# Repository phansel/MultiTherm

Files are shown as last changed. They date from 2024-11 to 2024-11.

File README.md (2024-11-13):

# MultiTherm
This repository contains the hardware, firmware, and drivers for MultiTherm.

MultiTherm allows you to log data from a few [tiny I2C temperature sensors](https://www.ti.com/lit/ds/symlink/tmp117.pdf) via your computer's USB port. A few could range from 1-4 or more.

Each temperature sensor is on a flexible 200mm probe ribbon; route them in free space however you like, or even trim their ribbons to length. An adhesive sticker provides thermal coupling to your device under test.

MultiTherm can be used as a lower-cost substitute for a resistance temperature detector (RTD) and data acquisition interface (DAQ) while still featuring NIST-traceable calibration accurate within ±0.1°C (between –20°C to 50°C) and 0.0078°C read-out resolution.

Working temperature range is –55 °C to 150 °C.

MultiTherm will be made available for purchase at a later date.

## Applications
- Optical bench temperature compensation
- Bulk material conductivity measurement
- Power electronics testing and characterization
- Chemical synthesis
- Bioreactors, polymerase chain reaction
- Wearable devices

## Project structure
- ESP32C6 firmware: [mt-fw](./mt-fw)
- PCB design files: [mt-hw](./mt-hw)
- Userspace serial-to-npyz driver: [mt-relay](./mt-relay)
- Project roadmap: [ROADMAP.md](./ROADMAP.md)

## License
[GPLv3](./LICENSE)

## Copyright
[Paul Hansel](https://paulhansel.com), 2024

## Thanks to:
- [Rust on ESP community](https://github.com/esp-rs)
- [KiCAD developers](https://www.kicad.org/sponsors/sponsors/)
- [Rust Embedded Working Group](https://blog.rust-embedded.org/)

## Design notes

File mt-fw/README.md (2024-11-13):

# MultiTherm ESP32C6 firmware

To build: `cargo build --release` or `./d.sh`

To flash: `cargo run --release` or `./r.sh`

Pinout for ESP32C6:
- I2C SDA: IO19, 
- I2C SCL: IO20

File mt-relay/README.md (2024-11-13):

# MultiTherm serial-to-npz relay

Converts an incoming stream of data from a MultiTherm connected over USB serial to a NumPy Zip ([npyz](https://numpy.org/doc/stable/reference/generated/numpy.lib.format.html)).

Bill of Materials:
- [serialport](https://github.com/serialport/serialport-rs) = "4.6.0"
- [nalgebra](https://docs.rs/nalgebra/latest/nalgebra/) = "0.33.2"
- [npyz](https://github.com/ExpHP/npyz) = "0.8"

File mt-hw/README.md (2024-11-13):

# MultiTherm Hardware
Printed circuit board and flex PCB design files.

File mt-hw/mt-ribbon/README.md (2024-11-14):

# MultiTherm Ribbon
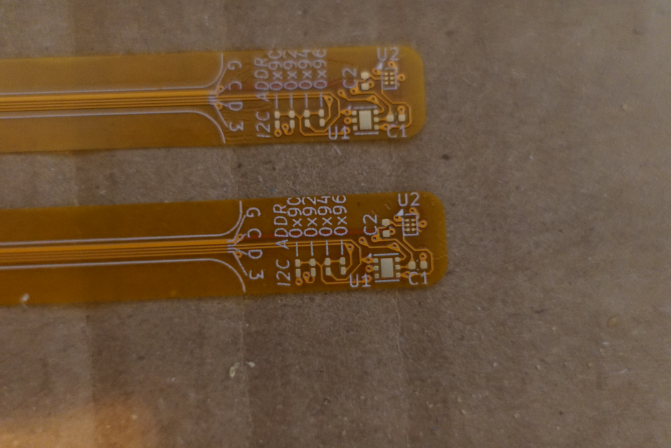
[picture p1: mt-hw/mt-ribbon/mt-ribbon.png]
Unpopulated mt-ribbon flex PCB


Individual ribbon cable flex PCB with temperature probe on the end.

Device address is configurable via solderable jumpers.

Supports WSON-6 (TMP117xxDRV) and DSBGA (TMP117xxYBG) packages. Populate one.

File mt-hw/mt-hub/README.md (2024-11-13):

# MultiTherm Hub
A hub for multiple MultiTherm probe ribbons.

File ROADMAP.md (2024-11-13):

# Roadmap
[X] Complete initial requirements document
[X] Publish PCB schematic and layout (GPLv3)
[X] Publish firmware (GPLv3)
[X] Publish userspace driver (GPLv3)
[ ] Project write-up
[ ] Ship integrated product (USB hub PCB, ribbons, documentation) to market

## Hardware
[X] Ribbon probe PCB schematic
[X] Ribbon probe PCB layout
[X] Fabricate and validate probe ribbon PCB (Rev 1.0)
[ ] Fabricate and validate probe ribbon PCB (Rev 1.2)
[ ] Model thermal resistance parameters of probe ribbon
[ ] Characterize thermal resistance of probe ribbon
[ ] Convert pin headers on probe ribbon to FFC
[ ] Write requirements for sensor hub: USB port, MCU, 0.1" headers, pull-up resistors, flat flex connectors.
[ ] Part selection for sensor hub
[ ] Sensor hub PCB schematic
[ ] Sensor hub PCB layout
[ ] Fabricate and validate sensor hub PCB

## Firmware
[X] Write minimal TMP117 driver
[X] Complete serial data format specification
[X] Write microcontroller firmware bridging TMP117 to serial (ESP32C6)
[ ] Replace ad-hoc TMP117 driver with [tmp117-rs](https://github.com/xgroleau/tmp117-rs)
[ ] Port firmware to lower-cost USB-serial microcontrollers: RP2040/RP2350/CH32V

## Software
[X] Write userspace driver bridging serial stream to .npyz timeseries with Unix timestamp
[X] Validate userspace driver end-to-end with application
[ ] Generalize userspace driver to remove assumption of three sensors
[ ] Create udev rules to automatically start and stop userspace driver when device is connected
[ ] Validate that udev rules behave as expected
[ ] Make userspace driver persistent to device serial connection interruptions: don't reset timeseries
[ ] Enable [atomic filesystem writes](https://github.com/danburkert/fs2-rs) for serial-to-file userspace driver 
[ ] Convert userspace driver to [kernel space driver](https://not-matthias.github.io/posts/kernel-driver-with-rust-2022/)
[ ] Add macOS and Windows support

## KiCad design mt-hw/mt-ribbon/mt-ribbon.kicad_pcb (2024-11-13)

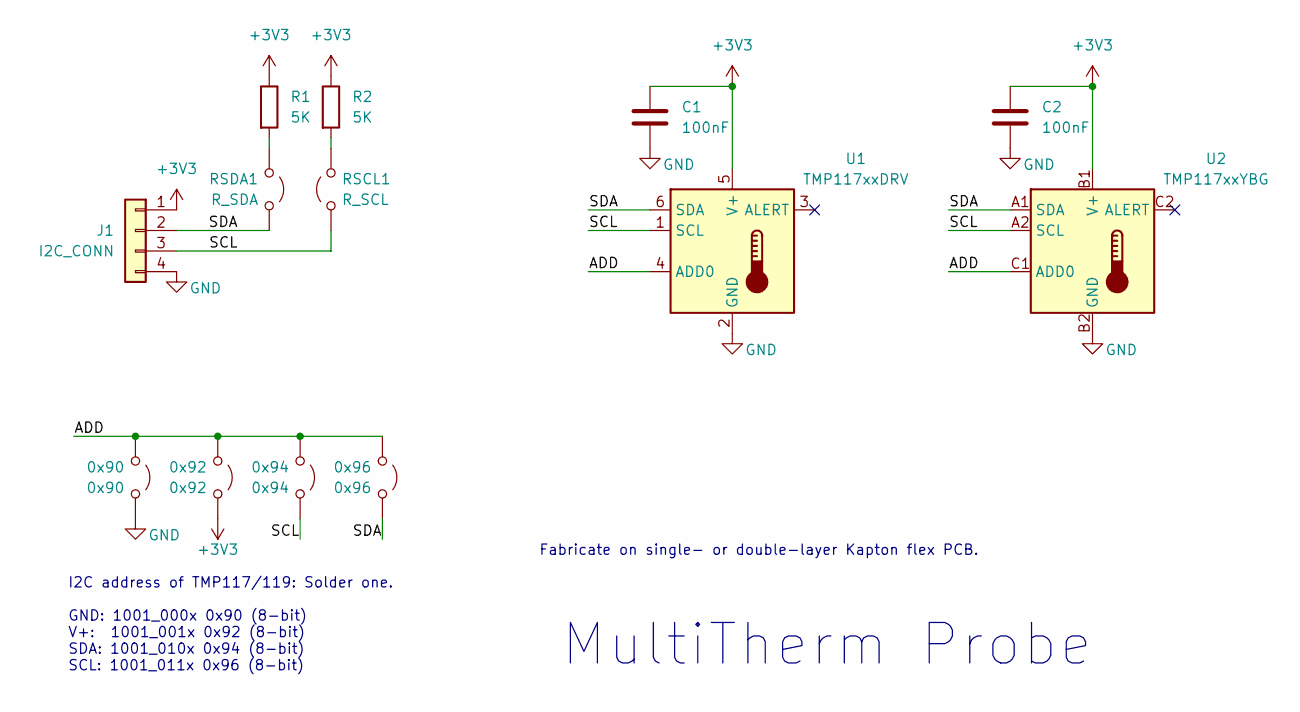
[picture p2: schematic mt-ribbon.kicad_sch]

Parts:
0x90: 0x90; SolderJumper-2_P0.43mm_Open_Pad0.3x0.75mm
0x92: 0x92; SolderJumper-2_P0.43mm_Open_Pad0.3x0.75mm
0x94: 0x94; SolderJumper-2_P0.43mm_Open_Pad0.3x0.75mm
0x96: 0x96; SolderJumper-2_P0.43mm_Open_Pad0.3x0.75mm
C1, C2: 100nF; C_0402_1005Metric
J1: I2C_CONN; PinHeader_1x04_P2.54mm_Vertical
R1, R2: 5K; R_0402_1005Metric_Pad0.72x0.64mm_HandSolder
RSCL1: R_SCL; SolderJumper-2_P0.43mm_Open_Pad0.3x0.75mm
RSDA1: R_SDA; SolderJumper-2_P0.43mm_Open_Pad0.3x0.75mm
U1: TMP117xxDRV; WSON-6-1EP_2x2mm_P0.65mm_EP1x1.6mm
U2: TMP117xxYBG; Texas_DSBGA-6_0.95x1.488mm_Layout2x3_P0.4mm

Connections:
+3V3: 0x92.1 (A), C1.1, C2.1, J1.1, R1.1, R2.1, U1.5 (V+), U2.B1 (V+)
/ADD: 0x90.2 (B), 0x92.2 (B), 0x94.2 (B), 0x96.2 (B), U1.4 (ADD0), U2.C1 (ADD0)
/SCL: 0x94.1 (A), J1.3, RSCL1.1 (A), U1.1 (SCL), U2.A2 (SCL)
/SDA: 0x96.1 (A), J1.2, RSDA1.1 (A), U1.6 (SDA), U2.A1 (SDA)
GND: 0x90.1 (A), C1.2, C2.2, J1.4, U1.2 (GND), U2.B2 (GND)
unnamed: R2.2, RSCL1.2 (B)
unnamed: R1.2, RSDA1.2 (B)

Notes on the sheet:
I2C address of TMP117/119: Solder one. GND: 1001_000x 0x90 (8-bit) V+: 1001_001x 0x92 (8-bit) SDA: 1001_010x 0x94 (8-bit) SCL: 1001_011x 0x96 (8-bit)
Fabricate on single- or double-layer Kapton flex PCB.
MultiTherm Probe

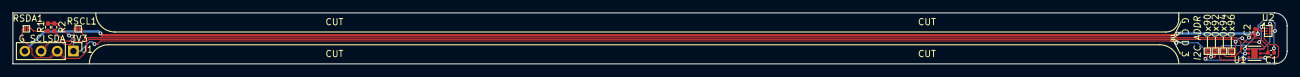
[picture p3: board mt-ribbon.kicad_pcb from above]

Board: 2 copper layers, 200.0 x 8.0 mm, 13 parts (0 on the bottom side), 7 nets.

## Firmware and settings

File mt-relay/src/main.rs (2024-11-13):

// Read temperatures sequentially from serial
// Write array sequence to files (/tmp/tempdataline) as npyz
// Other programs can read npyz periodically as required

use serialport;
use std::io::BufRead;
use std::io::BufReader;
use std::time::{Duration, Instant, SystemTime, UNIX_EPOCH};

use std::vec::Vec;

// TODO: flush samples more intelligently
const TSAMPS_FLUSH_THRESH: usize = 1500;
const TSAMPS_FLUSH_TARGET: usize = 1025;
const TDIFF_CUTOFF_MS: u128 = 750; // fudge factor

fn main() {
    let mut temp_seq: [[u16; 3]; 16] = [[0; 3]; 16];

    let serialport = "/dev/ttyACM0";
    let bitrate = 115200;
    let data_filename = "/tmp/tempdataline";

    // timestamp durations in the past
    // should be reconstructed / interpolated from existing values
    let time_samples_dt = [
        0.0, 1.0, 2.0, 4.0, 8.0, 16.0, 32.0, 64.0, 128.0, 256.0, 512.0, 1024.0, 2048.0, 4096.0,
        8192.0, 16384.0,
    ];

    // whether each of the samples in the line is valid (if not valid, set to 0)
    let mut time_samples_valid = [0_u8; 16];

    println!("Launching serial tempdata relay!");

    let mut tsamps: Vec<(std::time::Instant, [u16; 3])> = Vec::new();

    let serial_port = serialport::new(serialport, bitrate)
        .timeout(Duration::from_millis(1000))
        .open()
        .expect("Failed to open serial port.");

    let mut reader = BufReader::new(serial_port);

    // TODO: remove coupling to three sensors
    let addr_arr = [0x48_u8, 0x49_u8, 0x4A_u8];

    let mut buffer = "".to_string(); // enough bytes to read one line of temp samples
    loop {
        buffer = "".to_string();
        let read = reader.read_line(&mut buffer).unwrap();
        let current_time = Instant::now();
        let actual_now = SystemTime::now()
            .duration_since(UNIX_EPOCH)
            .expect("Time went backwards")
            .as_secs() as u128;

        let x = string_to_temps(buffer);

        let y = map_tr_to_arr(x, addr_arr);

        if let Some(y) = y {
            tsamps.push((current_time, y));
            (tsamps, temp_seq) = process_samples(tsamps, &time_samples_dt, &mut time_samples_valid);
            match write_ts_data_file(data_filename.to_string(), actual_now, temp_seq) {
                Ok(_) => {}
                Err(e) => {
                    panic!("Fault: {e}");
                }
            }
        }
    }
}

/*
Example output from the serial port:
[48:1606][49:1665][4a:1314]
[48:1606][49:1666][4a:1313]
[48:1606][49:1666][4a:1313]
temp at 0x48: 40.632813 C
temp at 0x49: 33.992188 C
temp at 0x4a: 24.695313 C

*/



#[derive(npyz::Serialize, npyz::Deserialize, npyz::AutoSerialize, Debug, PartialEq, Clone)]
pub struct SampleBlob {
    // TODO: remove coupling to three sensors
    arr: [[u16; 3]; 16],
    timestamp: [u32; 4],
}

// docs: https://docs.rs/npyz/latest/npyz/
pub fn write_ts_data_file(fname: String, ts: u128, arr: [[u16; 3]; 16]) -> std::io::Result<()> {
    // TODO: remove coupling to three sensors
    let mut out_buf: Vec<SampleBlob> = vec![];
    let mut structs = vec![];

    let tsu32 = [
        ts as u32,
        (ts >> 32) as u32,
        (ts >> 64) as u32,
        (ts >> 96) as u32,
    ];

    let calBlob = SampleBlob {
        arr: arr,
        timestamp: tsu32,
    };

    structs.push(calBlob);

    npyz::to_file_1d(fname.to_string(), structs)?;

    Ok(())
}

pub fn process_samples(
    mut tsamps: Vec<(std::time::Instant, [u16; 3])>,
    sample_deltas: &[f32; 16],
    mut mask_valid: &mut [u8; 16],
) -> (Vec<(std::time::Instant, [u16; 3])>, [[u16; 3]; 16]) {
    // TODO: remove coupling to three sensors
    let mut temp_hist_arr = [[0xFFFF_u16; 3]; 16];

    let time_now = Instant::now();

    // sample the data points and interpolate, and also cull extra points if over 1000
    if tsamps.len() > TSAMPS_FLUSH_THRESH {
        let mut tsamps_new: Vec<(std::time::Instant, [u16; 3])> = Vec::new();
        let todrain = TSAMPS_FLUSH_TARGET;

        for i in 0..todrain {
            tsamps_new.push(tsamps[i + todrain - 1]);
        }
        tsamps = tsamps_new;
    }

    // wipe out the mask if we don't have samples back then
    let oldest_delta = ((time_now - tsamps[0].0).as_millis() as f32) / 1000.0;
    let mut n_valid = 0;
    for i in 0..mask_valid.len() {
        if sample_deltas[i] > oldest_delta {
            mask_valid[i] = false as u8;
        } else {
            mask_valid[i] = true as u8;
            n_valid += 1;
        }
    }

    // sample tsamps at sample_deltas offsets from time_now
    // is this inefficient? why not
    for i in 0..n_valid {
        let target_tdiff = (sample_deltas[i] * 1000.0) as u128;
        for (time, tempvals) in &tsamps {
            if ((time_now - *time).as_millis() - target_tdiff) < TDIFF_CUTOFF_MS {
                temp_hist_arr[i] = *tempvals;
                break;
            }
        }
        if temp_hist_arr[i] == [0xFFFF_u16; 3] {
            // todo: if we didn't get it with nearest neighbor, try interp
            // println!("Didn't get it on n{}", i);
        }
    }

    return (tsamps, temp_hist_arr);
}

pub fn map_tr_to_arr(temps: [(u8, u16); 3], addr_arr: [u8; 3]) -> Option<[u16; 3]> {
    // TODO: remove coupling to three sensors
    let mut temps2 = [0_u16; 3];
    let mut incr = 0;
    for addr in addr_arr {
        for temp in temps {
            if temp.0 == addr {
                temps2[incr] = temp.1;
                incr += 1;
            }
        }
    }
    if incr == 3 {
        return Some(temps2);
    } else {
        return None;
    }
}

pub fn string_to_temps(instr: String) -> [(u8, u16); 3] {
    // TODO: remove coupling to three sensors
    let mut outdata = [(0_u8, 0_u16); 3];

    let instr = instr.trim();

    match instr.chars().nth(0) {
        Some('[') => {}
        _ => {
            println!("Not a valid string! Should probably error.");
            return [(0_u8, 0_u16); 3];
        }
    };

    match instr.chars().nth(26) {
        Some(']') => {}
        _ => {
            println!("Not a valid string! Should probably error.");
            return [(0_u8, 0_u16); 3];
        }
    };

    // [48:1606][49:1666][4a:1313]

    let (addr1, data1) = (&instr[1..3], &instr[4..8]);
    let (addr2, data2) = (&instr[10..12], &instr[13..17]);
    let (addr3, data3) = (&instr[19..21], &instr[22..26]);

    // println!("vals: {}_{}, {}_{}, {}_{}", addr1, data1, addr2, data2, addr3, data3);

    // now put it into outdata
    // convert each str to a u16 or u8
    outdata[0] = (
        u8::from_str_radix(addr1, 16).unwrap(),
        u16::from_str_radix(data1, 16).unwrap(),
    );
    outdata[1] = (
        u8::from_str_radix(addr2, 16).unwrap(),
        u16::from_str_radix(data2, 16).unwrap(),
    );
    outdata[2] = (
        u8::from_str_radix(addr3, 16).unwrap(),
        u16::from_str_radix(data3, 16).unwrap(),
    );

    // println!("outdata: {:x?}", outdata);
    return outdata;
}

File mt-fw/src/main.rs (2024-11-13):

#![no_std]
#![no_main]

use esp_backtrace as _;
use esp_hal::{delay::Delay, gpio::Io, i2c::I2c, prelude::*};

use esp_alloc as _;

use esp_println::print;
#[cfg(feature = "selftest")]
use esp_println::println;

enum Tmp117Addrs {
    Gnd = 0x90 >> 1,
    Vplus = 0x92 >> 1,
    Sda = 0x94 >> 1,
    Scl = 0x96 >> 1,
}

#[allow(dead_code)]
enum Tmp117Registers {
    TempResult = 0x00,
    Configuration = 0x01, // default 0x0220
    THighLimit = 0x02,
    TLowLimit = 0x03,
    EEPROMUL = 0x04,
    EEPROM1 = 0x05,
    EEPROM2 = 0x06,
    Tempoffset = 0x07,
    EEPROM3 = 0x08,
    DeviceId = 0x0F, // default value 0x0117
}

#[derive(Debug, Copy, Clone)]
struct Tmp117 {
    pub addr: u8,
    temp: [u8; 2],
}

impl Tmp117 {
    pub fn new(addr: u8) -> Self {
        Tmp117 {
            addr,
            temp: [0xFF; 2],
        }
    }

    #[allow(dead_code)]
    pub fn convert_u16_f32(inp: u16) -> f32 {
        // convert some u16 to the TMP117/119 format f32 for the Celsius temperature
        let temp = (inp as f32) * 0.0078125_f32;
        return temp;
    }

    pub fn oneshot<T: _esp_hal_i2c_Instance>(
        &mut self,
        i2c: &mut esp_hal::i2c::I2c<T, esp_hal::Blocking>,
        delay: &mut esp_hal::delay::Delay,
    ) -> Option<u16> {
        // set up oneshot by writing 0b11 MOD[1:0]
        let cfg_os: [u8; 2] = [0x00, 0b00000011];

        #[cfg(feature = "selftest")]
        println!("addr: {:x}", self.addr);
        let res = i2c.write(self.addr, &cfg_os);
        match res {
            Ok(_) => {}
            Err(_) => {
                #[cfg(feature = "selftest")]
                println!("couldn't trigger sample");
                return Some(0_u16);
            }
        }
        // wait 1ms for TMP117 to sample
        delay.delay(1.millis());

        // read from device to struct
        let mut tb: [u8; 2] = [0; 2];
        let rb = [Tmp117Registers::TempResult as u8];
        let res = i2c.write_read(self.addr, &rb, &mut tb);

        match res {
            Ok(_) => {
                for a in 0..2 {
                    self.temp[a] = tb[a];
                }
                let i16tmp: u16 = (self.temp[0] as u16) << 8 | (self.temp[1] as u16);
                return Some(i16tmp);
            }
            Err(_) => {
                #[cfg(feature = "selftest")]
                println!("couldn't write read");
                return None;
            }
        }
    }
}

#[entry]
fn main() -> ! {
    #[allow(unused)]
    let peripherals = esp_hal::init(esp_hal::Config::default());
    let mut delay = Delay::new();

    esp_println::logger::init_logger_from_env();

    let io = Io::new(peripherals.GPIO, peripherals.IO_MUX);

    // instantiate the i2c
    let mut i2c = I2c::new(peripherals.I2C0, io.pins.gpio19, io.pins.gpio20, 400.kHz());

    // create the vector of tmp117 units
    let mut ts_vec: [(Tmp117, bool); 4] = [
        (Tmp117::new(Tmp117Addrs::Gnd as u8), false),
        (Tmp117::new(Tmp117Addrs::Vplus as u8), false),
        (Tmp117::new(Tmp117Addrs::Sda as u8), false),
        (Tmp117::new(Tmp117Addrs::Scl as u8), false),
    ];

    // scan the bus and populate the vector with each responding TMP117
    use Tmp117Addrs::*;
    const POSSIBLE_ADDRESSES: [u8; 4] = [Gnd as u8, Vplus as u8, Sda as u8, Scl as u8];

    // check which devices are present on the bus (addresses 0x48-0x4b)
    for a in 0..4 {
        let address = POSSIBLE_ADDRESSES[a];
        let mut buf_dummy: [u8; 2] = [0; 2];
        let scan_buf: [u8; 1] = [Tmp117Registers::DeviceId as u8];
        match i2c.write_read(address, &scan_buf, &mut buf_dummy) {
            Ok(_) => {}
            Err(_e) => {
                #[cfg(feature = "selftest")]
                println!("FATAL {:?}: Initial I2C probe failed. Devices missing or I2C bus mis-terminated or shorted?", _e);
                panic!("Restarting.");
            }
        }

        match (buf_dummy[0], buf_dummy[1]) {
            (0x01, 0x17) => {
                // instantiate it
                ts_vec[a].1 = true;
                #[cfg(feature = "selftest")]
                println!("!! Device at {:x}", address);
            }
            _ => {
                #[cfg(feature = "selftest")]
                println!("No device at {:x}", address);
            }
        }
    }
    #[cfg(feature = "selftest")]
    log::info!("Entering main loop!");
    loop {
        for (mut sensor, val) in ts_vec {
            if val {
                let k = sensor.oneshot(&mut i2c, &mut delay).unwrap();
                print!("[{:02X}:{:04X}]", sensor.addr, k);
            }
        }
        print!("\r\n");
        delay.delay(500.millis());
    }
}

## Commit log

2024-11-13 Initial multitherm commit
    [mt-ribbon.kicad_pcb, mt-ribbon.kicad_sch]
2024-11-14 Add image of ribbon PCB

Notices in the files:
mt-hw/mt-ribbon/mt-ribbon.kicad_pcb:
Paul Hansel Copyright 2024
